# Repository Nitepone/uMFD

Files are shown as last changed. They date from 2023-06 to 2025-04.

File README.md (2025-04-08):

# uMFD: A small button pad for Pico

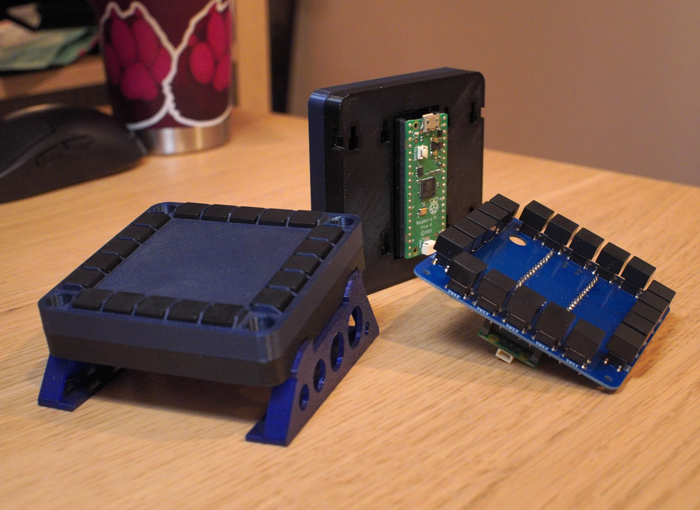
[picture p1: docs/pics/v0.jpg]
photo of hardware


This is a version 1.0 of my small mfd controller.

This repo contains the blender files for the case, along with kicad files for
the button carrier PCB, and the source code for the gamepad software.

The completed project appears as an xinput device where each of the 20 buttons
it its own digital input.

## Building

1. `mkdir build`
2. `cmake -B build`
3. `make -C build`
4. "Where is the final image?"
5. `find -name '*.uf2'`

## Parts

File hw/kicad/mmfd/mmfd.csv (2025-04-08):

# | Reference | Qty | Value | Footprint | DNP
1 | C1, C5, C6, C9, C10, C11, C12, C13, C14, C15 | 10 | 100nF | Capacitor_SMD:C_0402_1005Metric
2 | C2, C3 | 2 | 22pF | Capacitor_SMD:C_0402_1005Metric
3 | C4, C8, C16, C17 | 4 | 1uF | Capacitor_SMD:C_0402_1005Metric
4 | C7 | 1 | 10uF | Capacitor_SMD:C_0402_1005Metric
5 | F1 | 1 | 500mA | Fuse:Fuse_1206_3216Metric
6 | J1 | 1 | USB_C_Receptacle_USB2.0 | Connector_USB:USB_C_Receptacle_HRO_TYPE-C-31-M-12
7 | R1, R2, R7 | 3 | 1k | Resistor_SMD:R_0402_1005Metric
8 | R3, R4 | 2 | 5k1 | Resistor_SMD:R_0402_1005Metric
9 | R5, R6 | 2 | 27R | Resistor_SMD:R_0603_1608Metric
10 | U1 | 1 | W25Q128JVS | Package_SO:SOIC-8_5.23x5.23mm_P1.27mm
11 | U2 | 1 | USBLC6-2SC6 | Package_TO_SOT_SMD:SOT-23-6
12 | U3 | 1 | RP2040 | Sleep-Lib:RP2040-QFN-56
13 | U4 | 1 | XC6206PxxxMR-Regulator_Linear | Package_TO_SOT_SMD:SOT-23
14 | Y1 | 1 | 12MHz | Crystal:Crystal_SMD_3225-4Pin_3.2x2.5mm

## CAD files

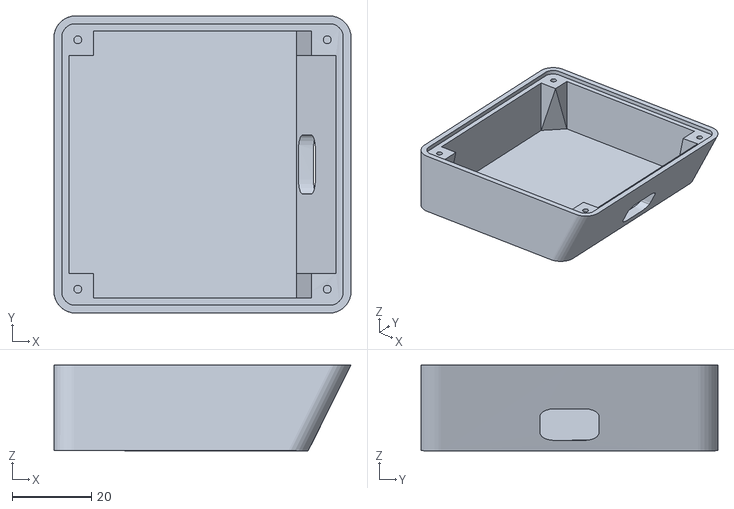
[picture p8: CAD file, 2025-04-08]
hw/blender/exports/umfd-full-v2-cleanup.stl
75.0 x 75.0 x 21.6

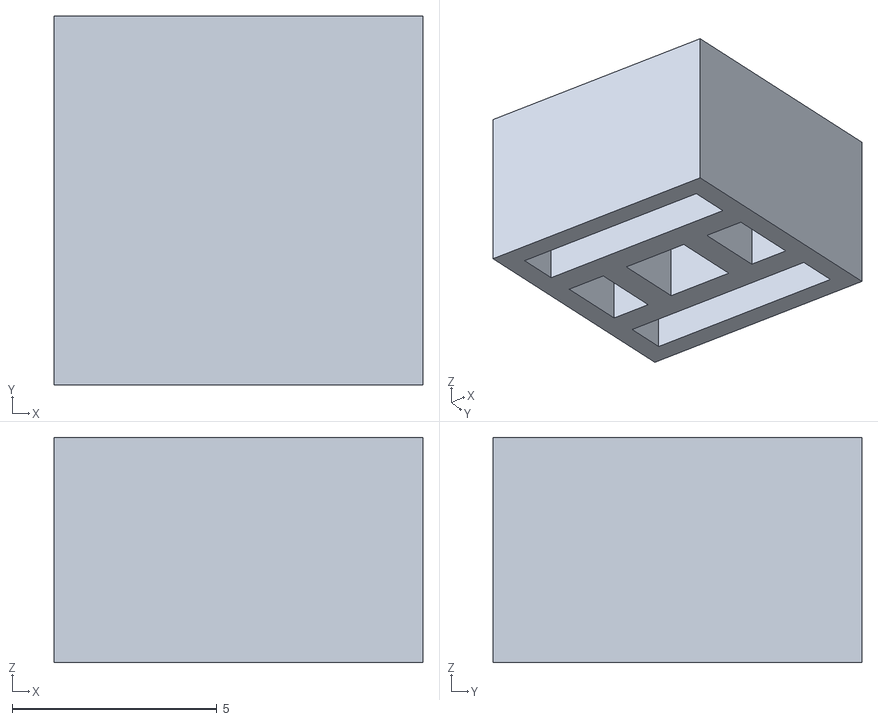
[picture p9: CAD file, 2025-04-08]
hw/blender/button.stl
9.00 x 9.00 x 5.50

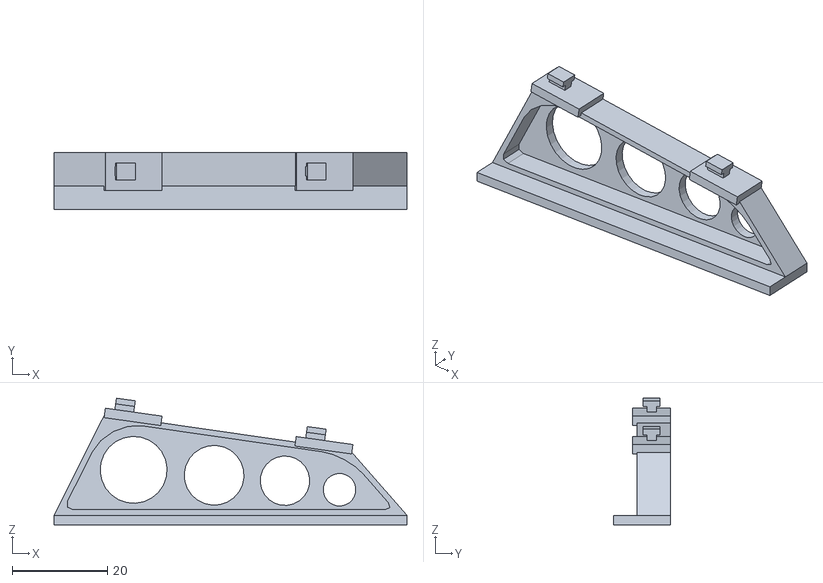
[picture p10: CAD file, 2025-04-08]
hw/blender/exports/umfd-mod-stand-v1-mirrored.stl
74.0 x 12.0 x 26.6

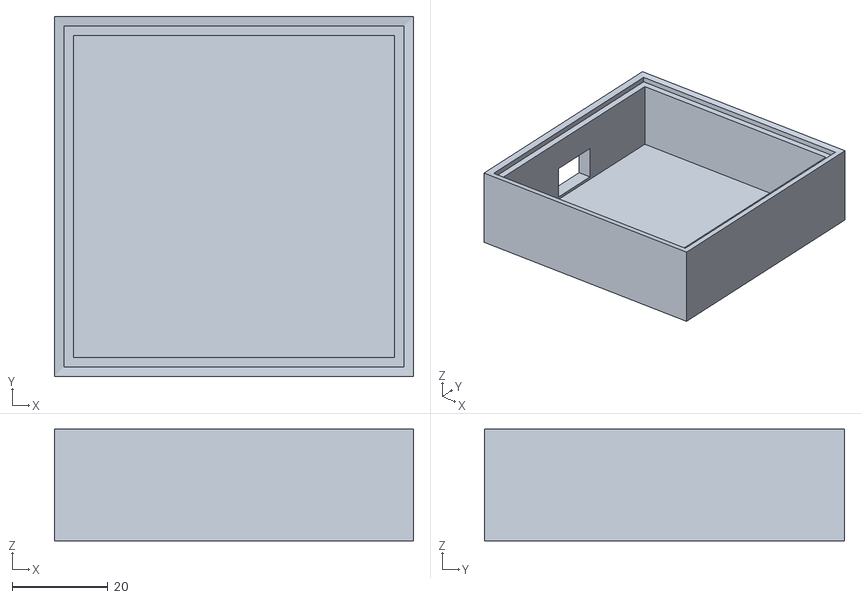
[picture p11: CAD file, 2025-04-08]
hw/kicad/untitled.stl
75.0 x 75.1 x 23.3

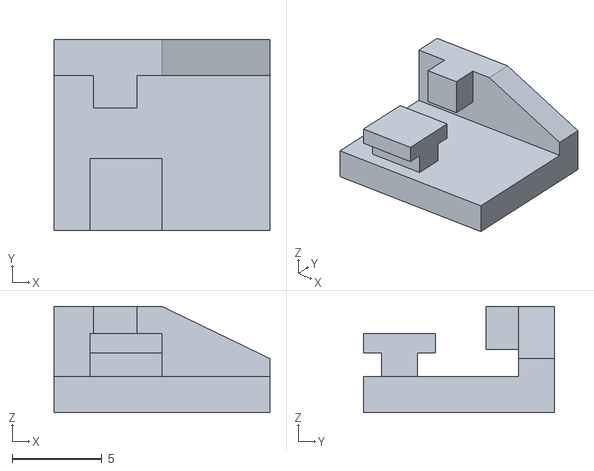
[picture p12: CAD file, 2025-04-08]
hw/blender/exports/test-mod-clip.stl
12.0 x 10.6 x 5.90

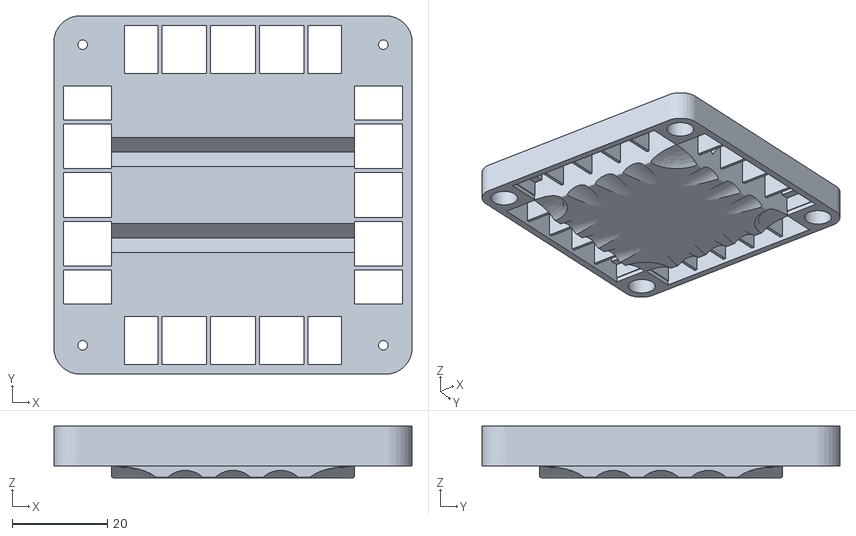
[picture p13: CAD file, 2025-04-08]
hw/blender/exports/umfd-top-cover-v3.2.stl
75.0 x 75.0 x 10.8

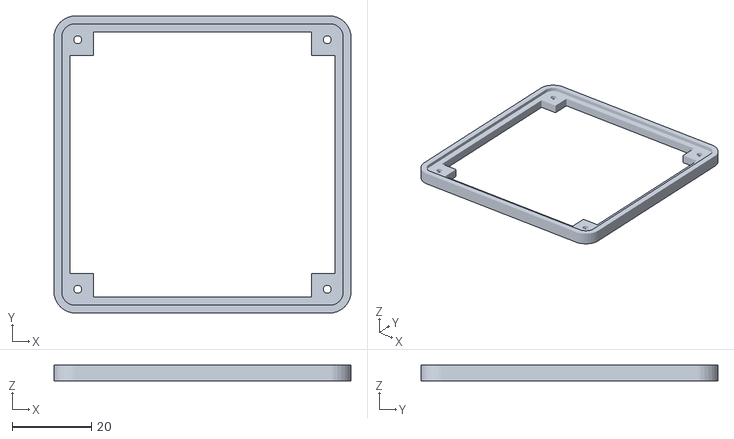
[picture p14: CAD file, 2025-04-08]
hw/blender/exports/umfd-top-v2.stl
75.0 x 75.0 x 4.00

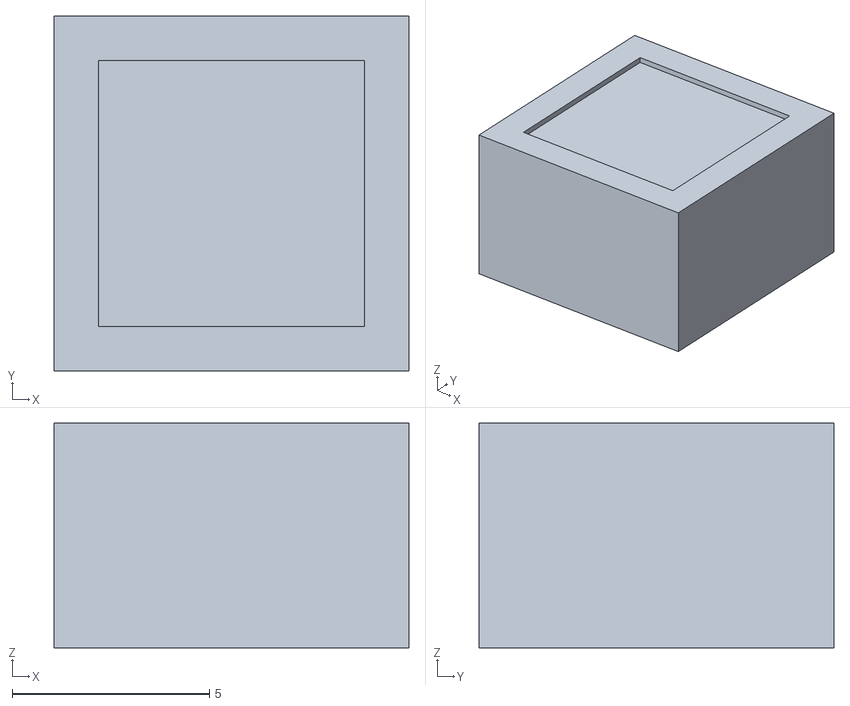
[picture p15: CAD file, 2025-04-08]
hw/blender/exports/button-v2.2.stl
9.00 x 9.00 x 5.70

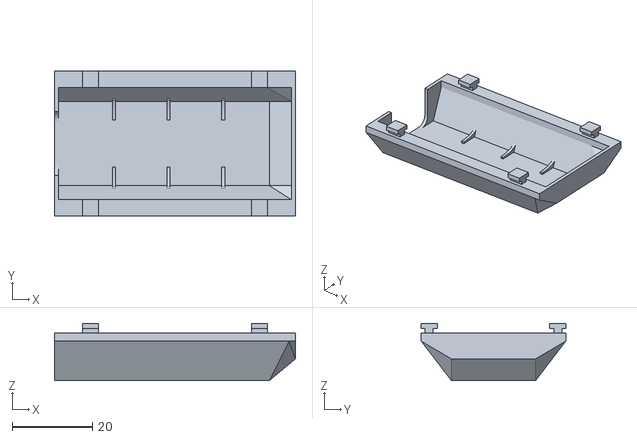
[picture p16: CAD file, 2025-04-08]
hw/blender/exports/umfd-mod-picap-v2.stl
60.0 x 36.0 x 14.2

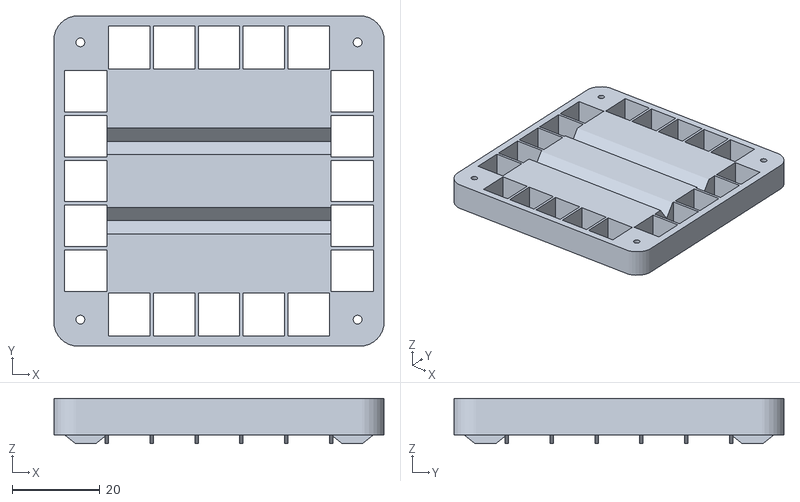
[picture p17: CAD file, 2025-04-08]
hw/blender/exports/umfd-top-cover-v3.3-cleanup.stl
75.0 x 75.0 x 10.3

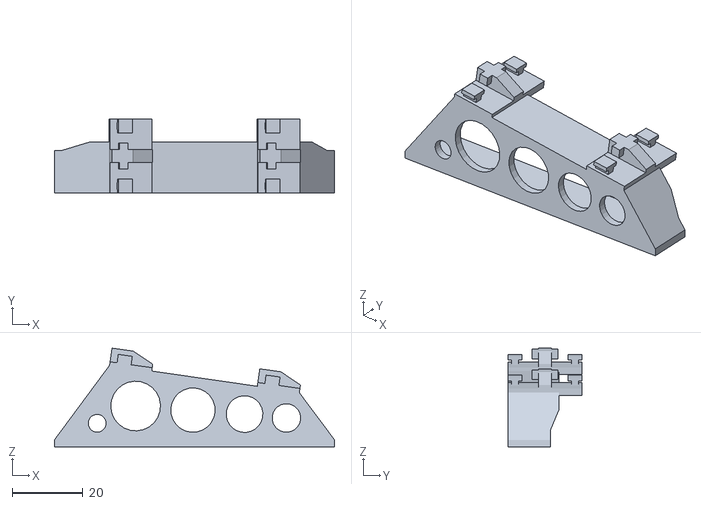
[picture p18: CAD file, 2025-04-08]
hw/blender/exports/umfd-mod-centerstand-v2.2.stl
79.0 x 21.0 x 27.9

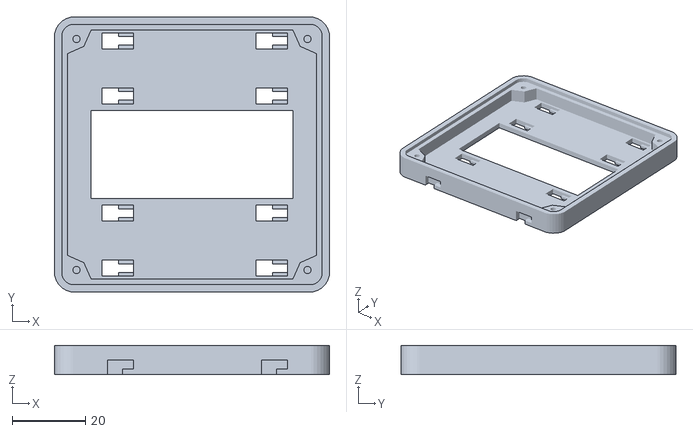
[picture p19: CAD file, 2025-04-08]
hw/blender/exports/umfd-mod-base-v2.stl
75.0 x 75.0 x 8.00

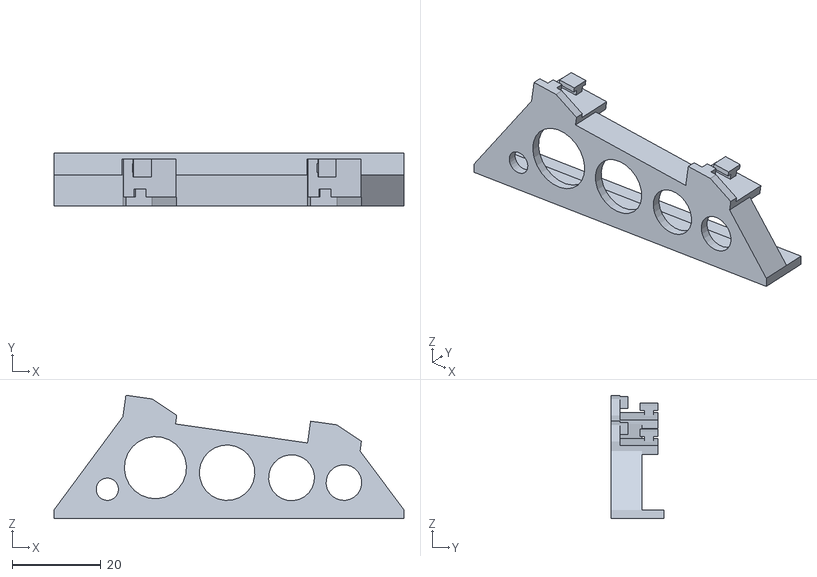
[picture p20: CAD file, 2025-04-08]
hw/blender/exports/umfd-mod-stand-v2.2.stl
79.0 x 12.0 x 27.9

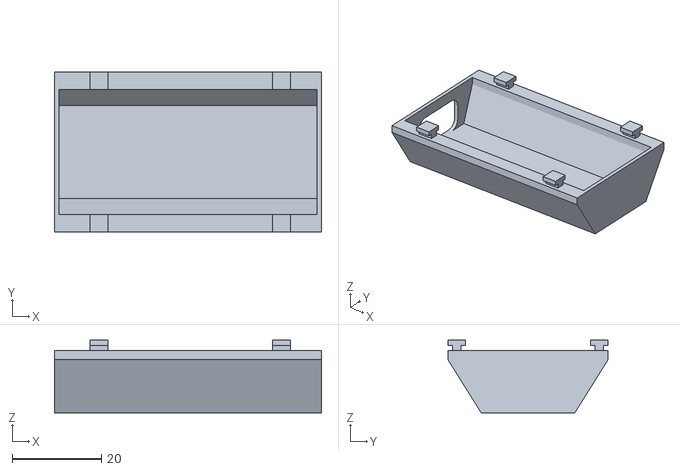
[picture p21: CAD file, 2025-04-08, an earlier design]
hw/blender/exports/umfd-mod-picap-v1.stl
60.0 x 36.0 x 16.4

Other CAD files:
hw/blender/exports/umfd-modular-top-v1.stl
hw/blender/exports/button-v2.1.stl
hw/blender/exports/umfd-mod-stand-v1.stl
hw/blender/exports/umfd-top-cover-v3.1.stl
hw/blender/button-v2.1.blend
hw/blender/button-v2.2.blend
hw/blender/button-v2.blend
hw/blender/button.blend
hw/blender/exports/button-v2.stl
hw/blender/exports/umfd-mod-stand-v2.stl
hw/blender/exports/umfd-top-cover-v1-cleanup.stl
hw/blender/exports/umfd-top-cover-v1.stl
hw/blender/exports/umfd-top-cover-v2-cleanup.stl
hw/blender/exports/umfd-top-cover-v2.1.stl
hw/blender/exports/umfd-top-cover-v3-cleanup.stl
hw/blender/exports/umfd-top-v1.1.stl
hw/blender/exports/umfd-top-v1.stl
hw/blender/umfd-full-v2-cleanup.blend
hw/blender/umfd-full-v2.1.blend
hw/blender/umfd-full-v2.blend
hw/blender/umfd-mod-base-v2.blend
hw/blender/umfd-mod-base-v2.stl
hw/blender/umfd-mod-centerstand-v2.2.blend
hw/blender/umfd-mod-picap-v1.blend
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

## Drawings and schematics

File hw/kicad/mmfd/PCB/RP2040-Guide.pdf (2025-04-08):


1 GPIO8 11 GPIO9 12 GPIO10 13 GPIO11 14 GPIO12 15 GPIO13 16 GPIO14 17 GPIO15 18 TESTEN 19 GPIO0 2 XTAL_IN 20 XTAL_OUT 21 SWCLK 24 SWDIO 25 ~{RUN} 26 GPIO16 27 GPIO17 28 GPIO18 29 GPIO1 3 GPIO19 30 GPIO20 31 GPIO21 32 GPIO22 34 GPIO23 35 GPIO24 36 GPIO25 37 GPIO26/ADC0 38 GPIO27/ADC1 39 GPIO2 4 GPIO28/ADC2 40 GPIO29/ADC3 41 ADC_AVDD 43 VREG_VIN 44 VREG_VOUT 45 D- 46 D+ 47 USB_VDD 48 GPIO3 5 DVDD 50 QSPI_SD3 51 QSPI_SCLK 52 QSPI_SD0 53 QSPI_SD2 54 QSPI_SD1 55 QSPI_SS_N 56 GND 57 GPIO4 6 GPIO5 7 GPIO6 8 GPIO7 9 U3 GND RP2040 +3.3V C6

File: RP2040-Guide.kicad_sch Sheet: / Sleepdealer

Id: 1/1 Title: RP2040 - Design Guide

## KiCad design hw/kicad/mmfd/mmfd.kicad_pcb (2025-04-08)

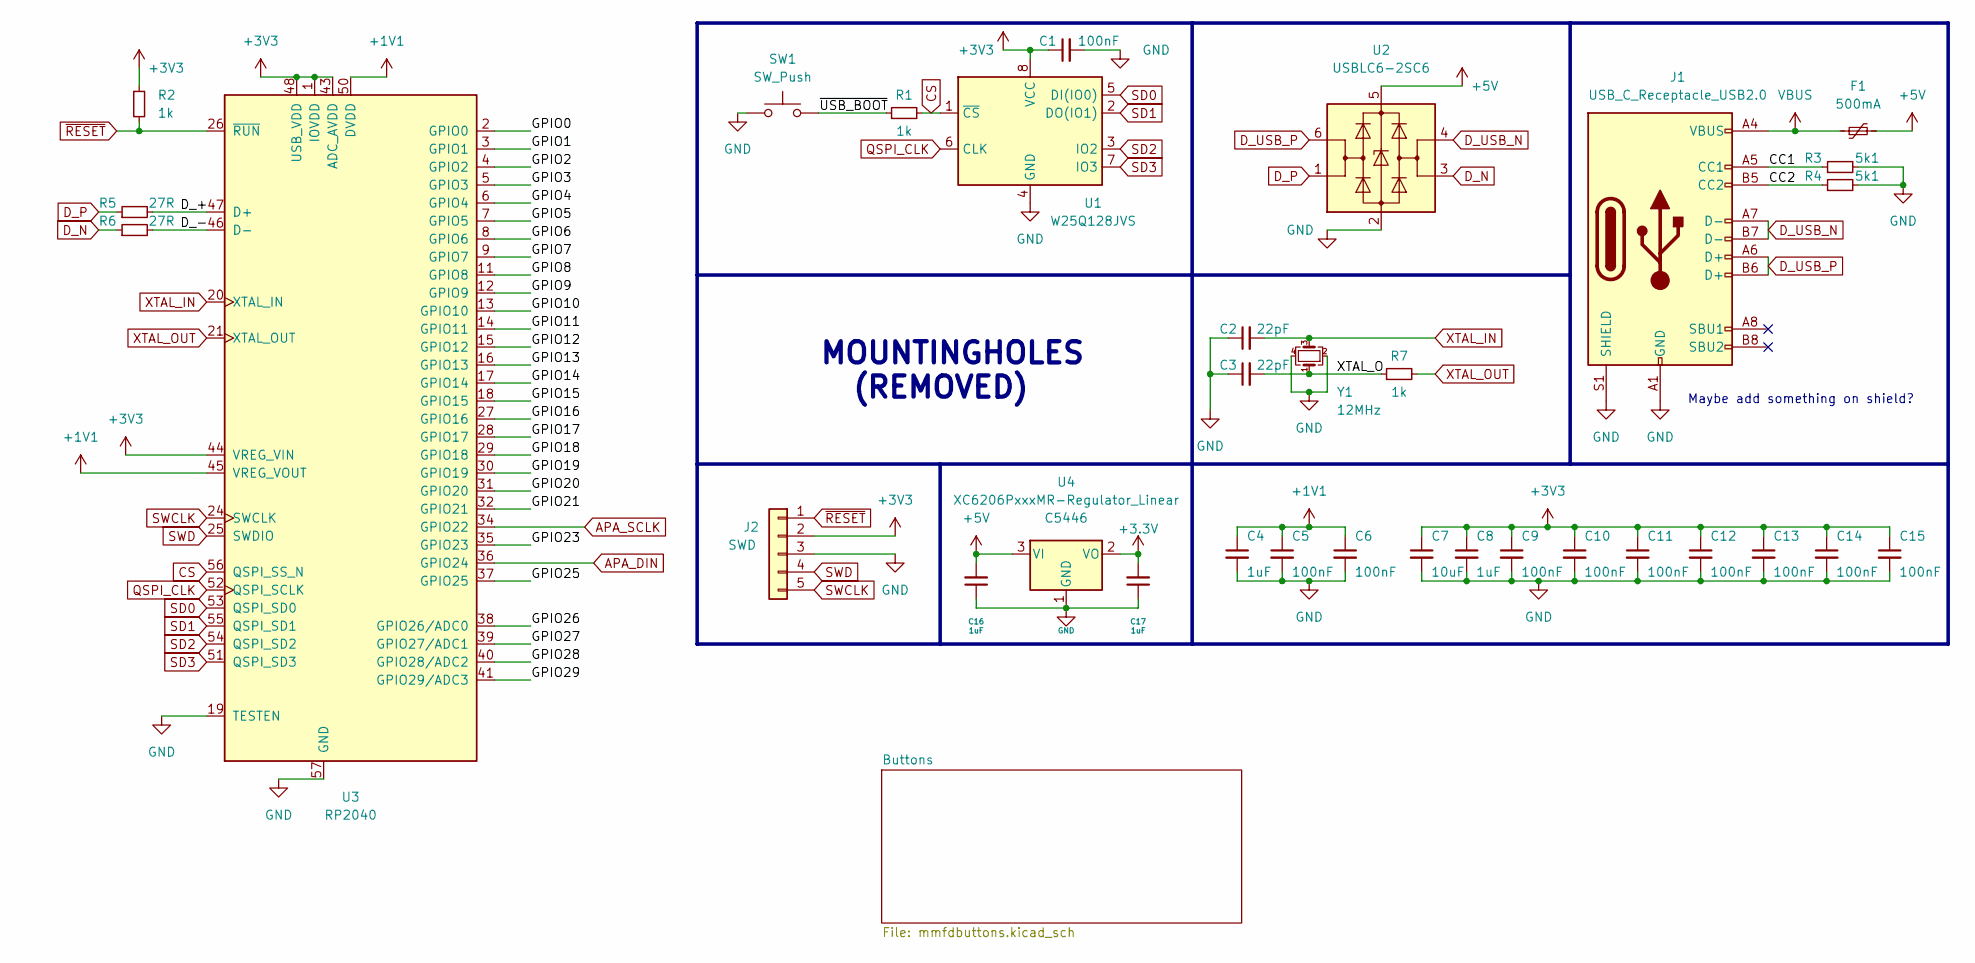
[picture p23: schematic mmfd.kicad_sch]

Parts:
C1, C5, C6, C9, C10, C11, C12, C13, C14, C15: 100nF; C_0402_1005Metric; LCSC C1525
C2, C3: 22pF; C_0402_1005Metric; LCSC C1555
C4, C8, C16, C17: 1uF; C_0402_1005Metric; LCSC C52923
C7: 10uF; C_0402_1005Metric; LCSC C15525
F1: 500mA; Fuse_1206_3216Metric; LCSC C70076
J1: USB_C_Receptacle_USB2.0; USB_C_Receptacle_HRO_TYPE-C-31-M-12; LCSC C165948
J2: SWD; PinSocket_1x05_P2.54mm_Vertical
R1, R2, R7: 1k; R_0402_1005Metric; LCSC C11702
R3, R4: 5k1; R_0402_1005Metric; LCSC C25905
R5, R6: 27R; R_0603_1608Metric; LCSC C25190
SW1: SW_Push; PinSocket_1x02_P2.54mm_Vertical
U1: W25Q128JVS; SOIC-8_5.23x5.23mm_P1.27mm; LCSC C131025
U2: USBLC6-2SC6; SOT-23-6; LCSC C2827654
U3: RP2040; RP2040-QFN-56; LCSC C2040
U4: XC6206PxxxMR-Regulator_Linear; SOT-23; LCSC C5446
Y1: 12MHz; Crystal_SMD_3225-4Pin_3.2x2.5mm; LCSC C9002

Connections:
+1V1: C4.1, C5.1, C6.1, U3.23 (DVDD), U3.45 (VREG_VOUT), U3.50 (DVDD)
+5V: C16.2, F1.2, U2.5 (VBUS), U4.3 (VI); also elsewhere on the board
/CC1: J1.A5 (CC1), R3.1
/CC2: J1.B5 (CC2), R4.1
/D_+: R5.2, U3.47 (D+)
/D_-: R6.2, U3.46 (D-)
/GPIO0: U3.2 (GPIO0)
/GPIO1: U3.3 (GPIO1)
/GPIO2: U3.4 (GPIO2)
/GPIO3: U3.5 (GPIO3)
/GPIO4: U3.6 (GPIO4)
/GPIO5: U3.7 (GPIO5)
/GPIO6: U3.8 (GPIO6)
/GPIO7: U3.9 (GPIO7)
/GPIO8: U3.11 (GPIO8)
/GPIO9: U3.12 (GPIO9)
/GPIO10: U3.13 (GPIO10)
/GPIO11: U3.14 (GPIO11)
/GPIO12: U3.15 (GPIO12)
/GPIO13: U3.16 (GPIO13)
/GPIO14: U3.17 (GPIO14)
/GPIO15: U3.18 (GPIO15)
/GPIO16: U3.27 (GPIO16)
/GPIO17: U3.28 (GPIO17)
/GPIO18: U3.29 (GPIO18)
/GPIO19: U3.30 (GPIO19)
/GPIO20: U3.31 (GPIO20)
/GPIO21: U3.32 (GPIO21)
/GPIO23: U3.35 (GPIO23)
/GPIO25: U3.37 (GPIO25)
/GPIO26: U3.38 (GPIO26/ADC0)
/GPIO27: U3.39 (GPIO27/ADC1)
/GPIO28: U3.40 (GPIO28/ADC2)
/GPIO29: U3.41 (GPIO29/ADC3)
/XTAL_O: C3.2, R7.1, Y1.1
APA_DIN: U3.36 (GPIO24); also elsewhere on the board
APA_SCLK: U3.34 (GPIO22); also elsewhere on the board
CS: R1.2, U1.1 (~CS), U3.56 (QSPI_SS_N)
D_N: R6.1, U2.3 (I/O2)
D_P: R5.1, U2.1 (I/O1)
D_USB_N: J1.A7 (D-), J1.B7 (D-), U2.4 (I/O2)
D_USB_P: J1.A6 (D+), J1.B6 (D+), U2.6 (I/O1)
QSPI_CLK: U1.6 (CLK), U3.52 (QSPI_SCLK)
SD0: U1.5 (DI(IO0)), U3.53 (QSPI_SD0)
SD1: U1.2 (DO(IO1)), U3.55 (QSPI_SD1)
SD2: U1.3 (IO2), U3.54 (QSPI_SD2)
SD3: U1.7 (IO3), U3.51 (QSPI_SD3)
SWCLK: J2.5, U3.24 (SWCLK)
SWD: J2.4, U3.25 (SWDIO)
VBUS: F1.1, J1.A4 (VBUS), J1.A9 (VBUS), J1.B4 (VBUS), J1.B9 (VBUS)
XTAL_IN: C2.2, U3.20 (XTAL_IN), Y1.3
XTAL_OUT: R7.2, U3.21 (XTAL_OUT)
~RESET: J2.1, R2.2, U3.26 (~RUN)

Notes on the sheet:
MOUNTINGHOLES (REMOVED)
Maybe add something on shield?

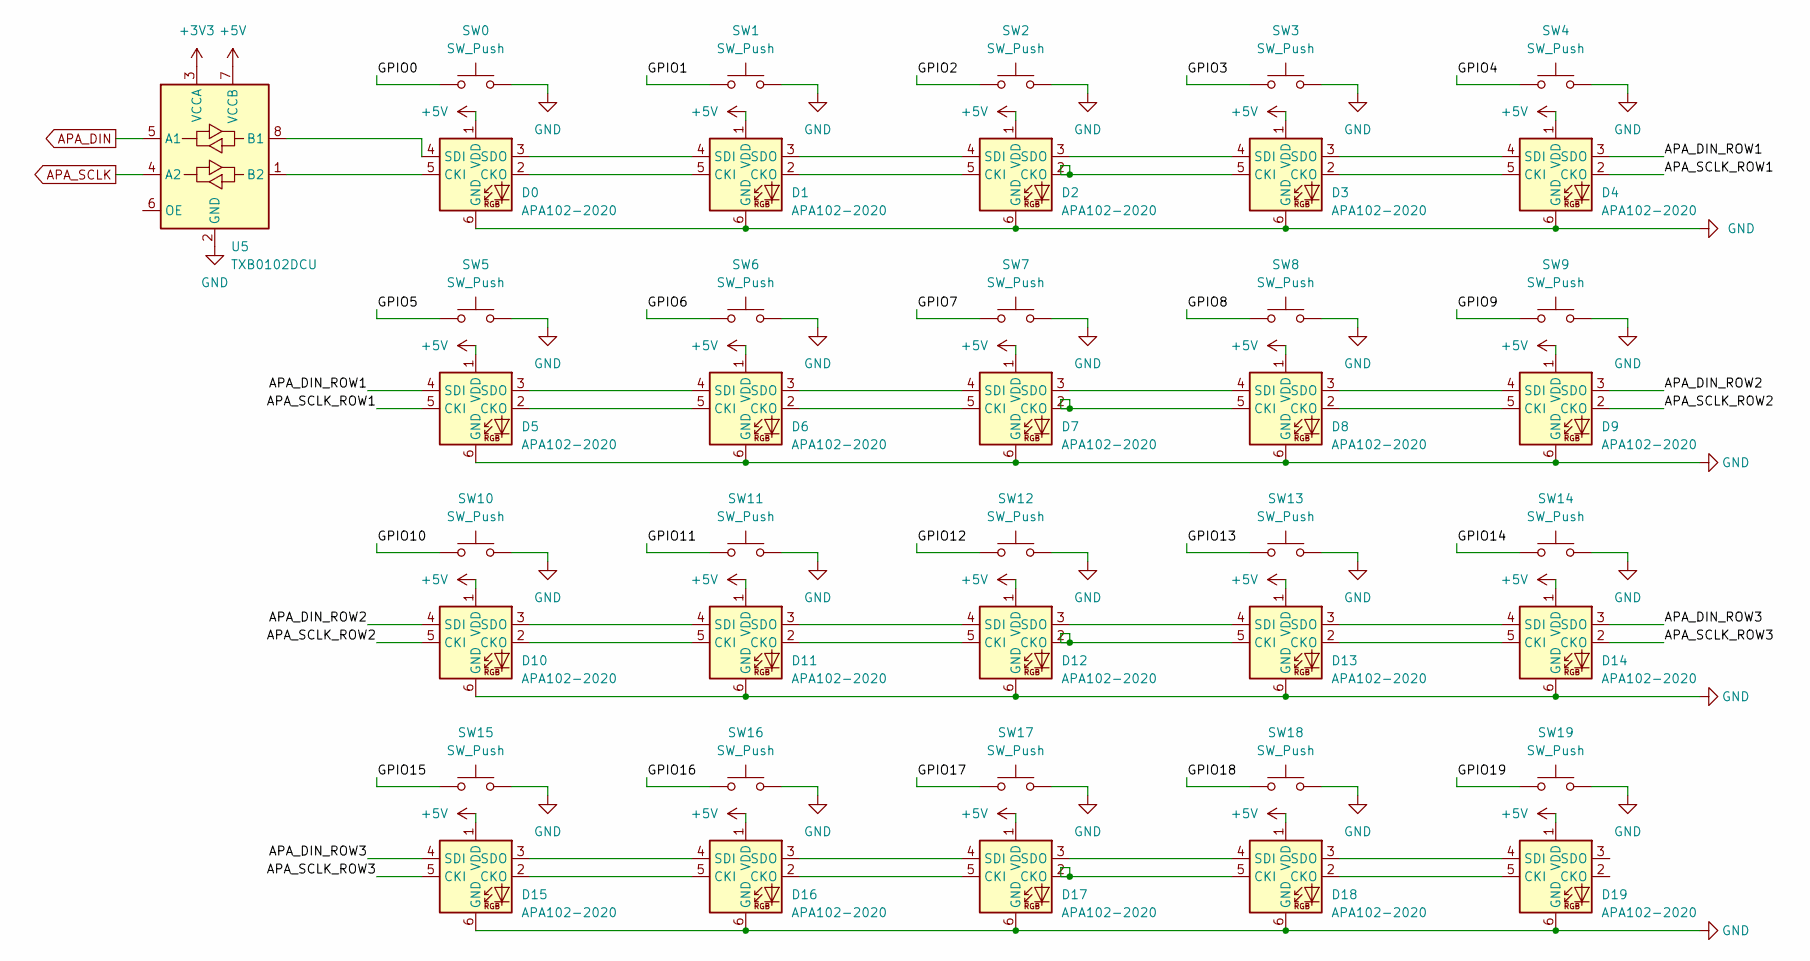
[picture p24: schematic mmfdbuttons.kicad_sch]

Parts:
D0, D1, D2, D3, D4, D5, D6, D7, D8, D9, D10, D11, D12, D13, D14, D15, D16, D17, D18, D19: APA102-2020; LED-APA102-2020
SW0, SW1, SW2, SW3, SW4, SW5, SW6, SW7, SW8, SW9, SW10, SW11, SW12, SW13, SW14, SW15, SW16, SW17, SW18, SW19: SW_Push; Kailh_socket_MX_optional
U5: TXB0102DCU; VSSOP-8_2.4x2.1mm_P0.5mm

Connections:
+5V: D0.1 (VDD), D1.1 (VDD), D2.1 (VDD), D3.1 (VDD), D4.1 (VDD), D5.1 (VDD), D6.1 (VDD), D7.1 (VDD), D8.1 (VDD), D9.1 (VDD), D10.1 (VDD), D11.1 (VDD), D12.1 (VDD), D13.1 (VDD), D14.1 (VDD), D15.1 (VDD), D16.1 (VDD), D17.1 (VDD), D18.1 (VDD), D19.1 (VDD), U5.7 (VCCB); also elsewhere on the board
/Buttons/APA_DIN_ROW1: D4.3 (SDO), D5.4 (SDI)
/Buttons/APA_DIN_ROW2: D9.3 (SDO), D10.4 (SDI)
/Buttons/APA_DIN_ROW3: D14.3 (SDO), D15.4 (SDI)
/Buttons/APA_SCLK_ROW1: D4.2 (CKO), D5.5 (CKI)
/Buttons/APA_SCLK_ROW2: D9.2 (CKO), D10.5 (CKI)
/Buttons/APA_SCLK_ROW3: D14.2 (CKO), D15.5 (CKI)
/Buttons/GPIO0: SW0.1
/Buttons/GPIO2: SW2.1
/Buttons/GPIO3: SW3.1
/Buttons/GPIO4: SW4.1
/Buttons/GPIO5: SW5.1
/Buttons/GPIO6: SW6.1
/Buttons/GPIO7: SW7.1
/Buttons/GPIO8: SW8.1
/Buttons/GPIO9: SW9.1
/Buttons/GPIO10: SW10.1
/Buttons/GPIO11: SW11.1
/Buttons/GPIO12: SW12.1
/Buttons/GPIO13: SW13.1
/Buttons/GPIO14: SW14.1
/Buttons/GPIO15: SW15.1
/Buttons/GPIO16: SW16.1
/Buttons/GPIO17: SW17.1
/Buttons/GPIO18: SW18.1
/Buttons/GPIO19: SW19.1
APA_DIN: U5.5 (A1); also elsewhere on the board
APA_SCLK: U5.4 (A2); also elsewhere on the board
unnamed: D0.5 (CKI), U5.1 (B2)
unnamed: D0.2 (CKO), D1.5 (CKI)
unnamed: D0.4 (SDI), U5.8 (B1)
unnamed: D0.3 (SDO), D1.4 (SDI)
unnamed: D1.2 (CKO), D2.5 (CKI)
unnamed: D1.3 (SDO), D2.4 (SDI)
unnamed: D2.2 (CKO), D3.5 (CKI)
unnamed: D2.3 (SDO), D3.4 (SDI)
unnamed: D3.2 (CKO), D4.5 (CKI)
unnamed: D3.3 (SDO), D4.4 (SDI)
unnamed: D5.2 (CKO), D6.5 (CKI)
unnamed: D5.3 (SDO), D6.4 (SDI)
unnamed: D6.2 (CKO), D7.5 (CKI)
unnamed: D6.3 (SDO), D7.4 (SDI)
unnamed: D7.2 (CKO), D8.5 (CKI)
unnamed: D7.3 (SDO), D8.4 (SDI)
unnamed: D8.2 (CKO), D9.5 (CKI)
unnamed: D8.3 (SDO), D9.4 (SDI)
unnamed: D10.2 (CKO), D11.5 (CKI)
unnamed: D10.3 (SDO), D11.4 (SDI)
unnamed: D11.2 (CKO), D12.5 (CKI)
unnamed: D11.3 (SDO), D12.4 (SDI)
unnamed: D12.2 (CKO), D13.5 (CKI)
unnamed: D12.3 (SDO), D13.4 (SDI)
unnamed: D13.2 (CKO), D14.5 (CKI)
unnamed: D13.3 (SDO), D14.4 (SDI)
unnamed: D15.2 (CKO), D16.5 (CKI)
unnamed: D15.3 (SDO), D16.4 (SDI)
unnamed: D16.2 (CKO), D17.5 (CKI)
unnamed: D16.3 (SDO), D17.4 (SDI)
unnamed: D17.2 (CKO), D18.5 (CKI)
unnamed: D17.3 (SDO), D18.4 (SDI)
unnamed: D18.2 (CKO), D19.5 (CKI)
unnamed: D18.3 (SDO), D19.4 (SDI)

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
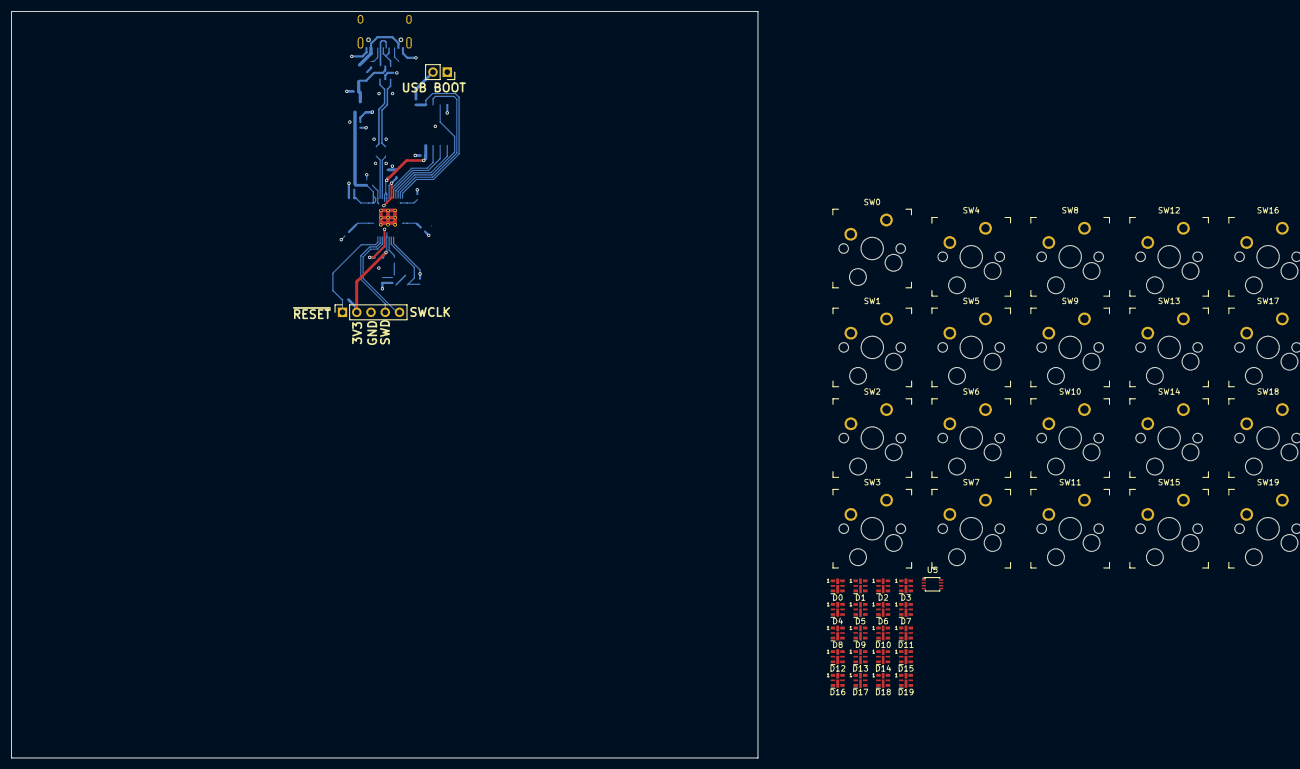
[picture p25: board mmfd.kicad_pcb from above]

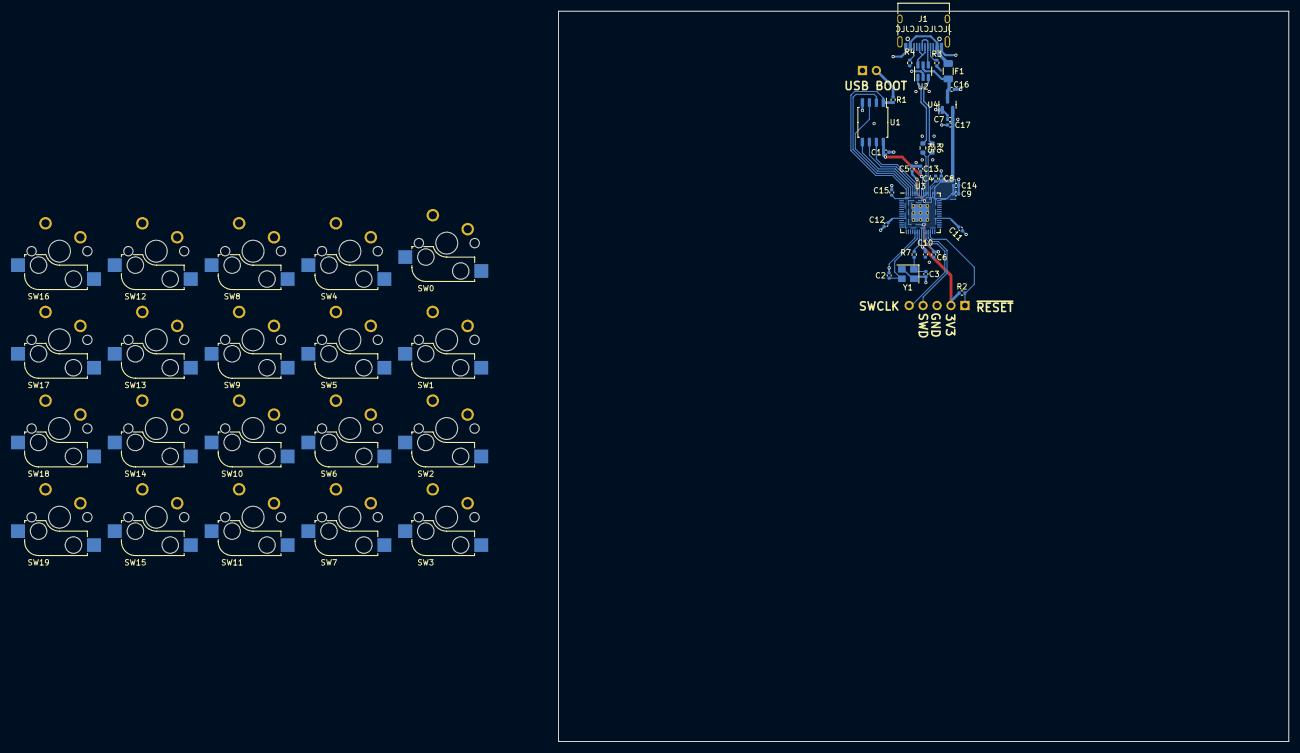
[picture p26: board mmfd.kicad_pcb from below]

Board: 2 copper layers, 133.0 x 133.0 mm, 74 parts (31 on the bottom side), 68 nets.

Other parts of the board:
SW20: SW_Push; PinSocket_1x02_P2.54mm_Vertical

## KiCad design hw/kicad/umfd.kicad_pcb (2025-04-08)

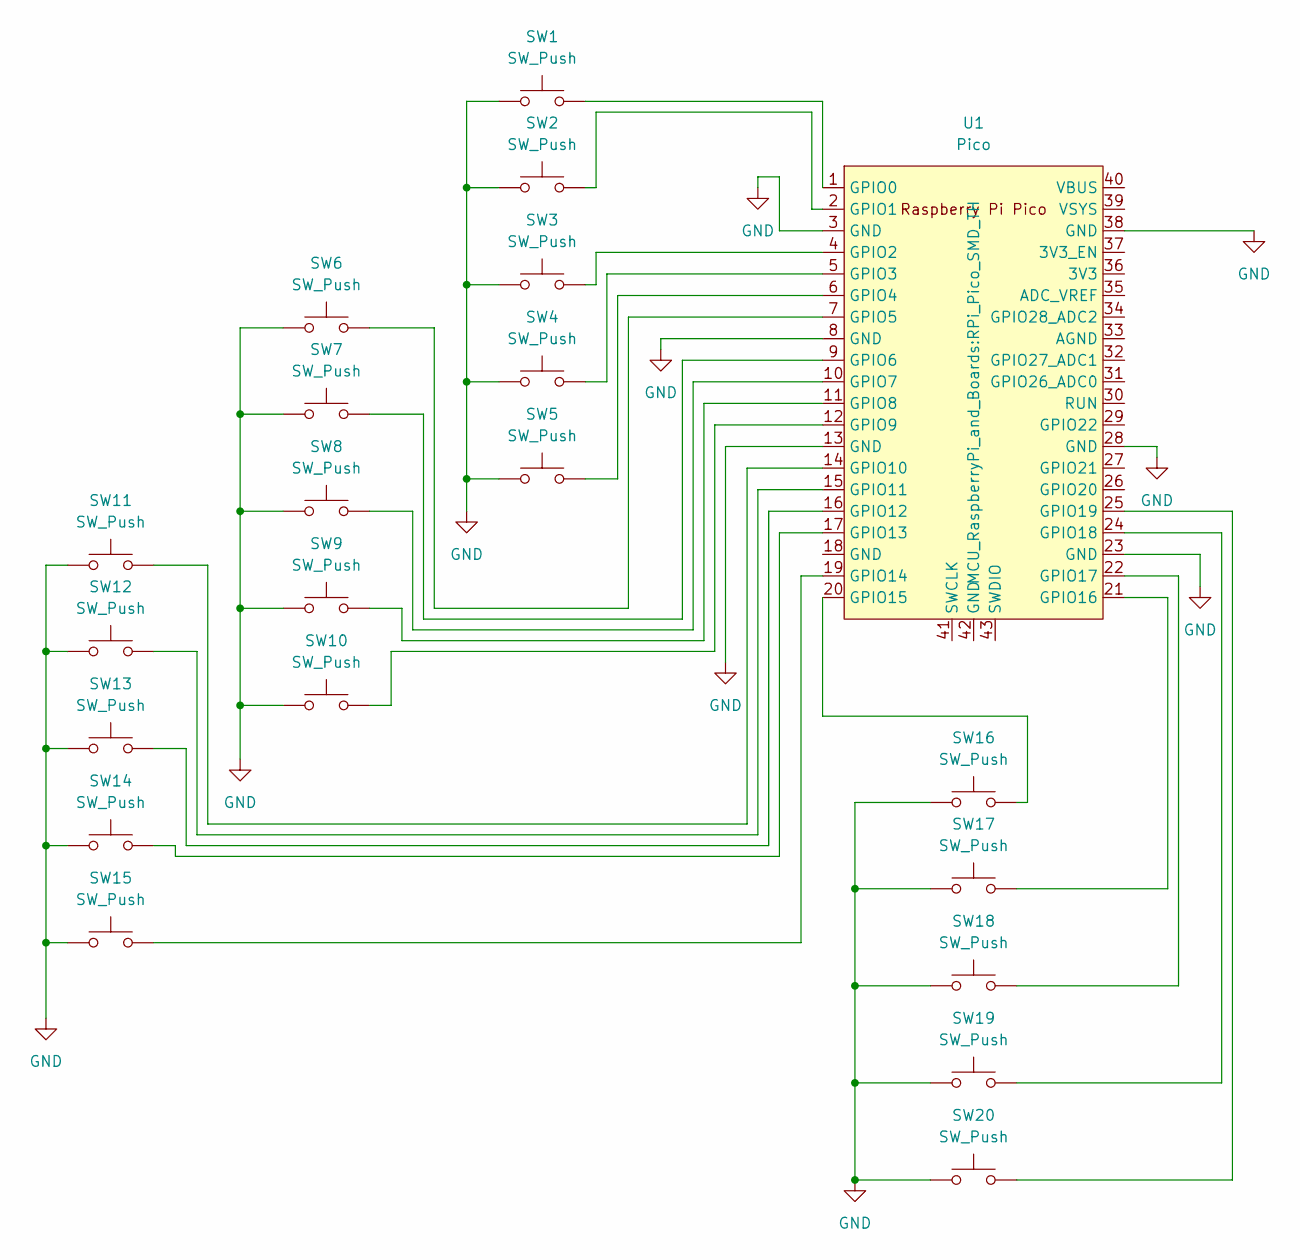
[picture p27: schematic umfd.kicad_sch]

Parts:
SW1, SW2, SW3, SW4, SW5, SW6, SW7, SW8, SW9, SW10, SW11, SW12, SW13, SW14, SW15, SW16, SW17, SW18, SW19, SW20: SW_Push; SW_PUSH_6mm
U1: Pico; RPi_Pico_SMD_TH

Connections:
GND: SW1.1, SW2.1, SW3.1, SW4.1, SW5.1, SW6.1, SW7.1, SW8.1, SW9.1, SW10.1, SW11.1, SW12.1, SW13.1, SW14.1, SW15.1, SW16.1, SW17.1, SW18.1, SW19.1, SW20.1, U1.3 (GND), U1.8 (GND), U1.13 (GND), U1.23 (GND), U1.28 (GND), U1.38 (GND)
unnamed: SW1.2, U1.1 (GPIO0)
unnamed: SW2.2, U1.2 (GPIO1)
unnamed: SW3.2, U1.4 (GPIO2)
unnamed: SW4.2, U1.5 (GPIO3)
unnamed: SW5.2, U1.6 (GPIO4)
unnamed: SW6.2, U1.7 (GPIO5)
unnamed: SW7.2, U1.9 (GPIO6)
unnamed: SW8.2, U1.10 (GPIO7)
unnamed: SW9.2, U1.11 (GPIO8)
unnamed: SW10.2, U1.12 (GPIO9)
unnamed: SW11.2, U1.14 (GPIO10)
unnamed: SW12.2, U1.15 (GPIO11)
unnamed: SW13.2, U1.16 (GPIO12)
unnamed: SW14.2, U1.17 (GPIO13)
unnamed: SW15.2, U1.19 (GPIO14)
unnamed: SW16.2, U1.20 (GPIO15)
unnamed: SW17.2, U1.21 (GPIO16)
unnamed: SW18.2, U1.22 (GPIO17)
unnamed: SW19.2, U1.24 (GPIO18)
unnamed: SW20.2, U1.25 (GPIO19)

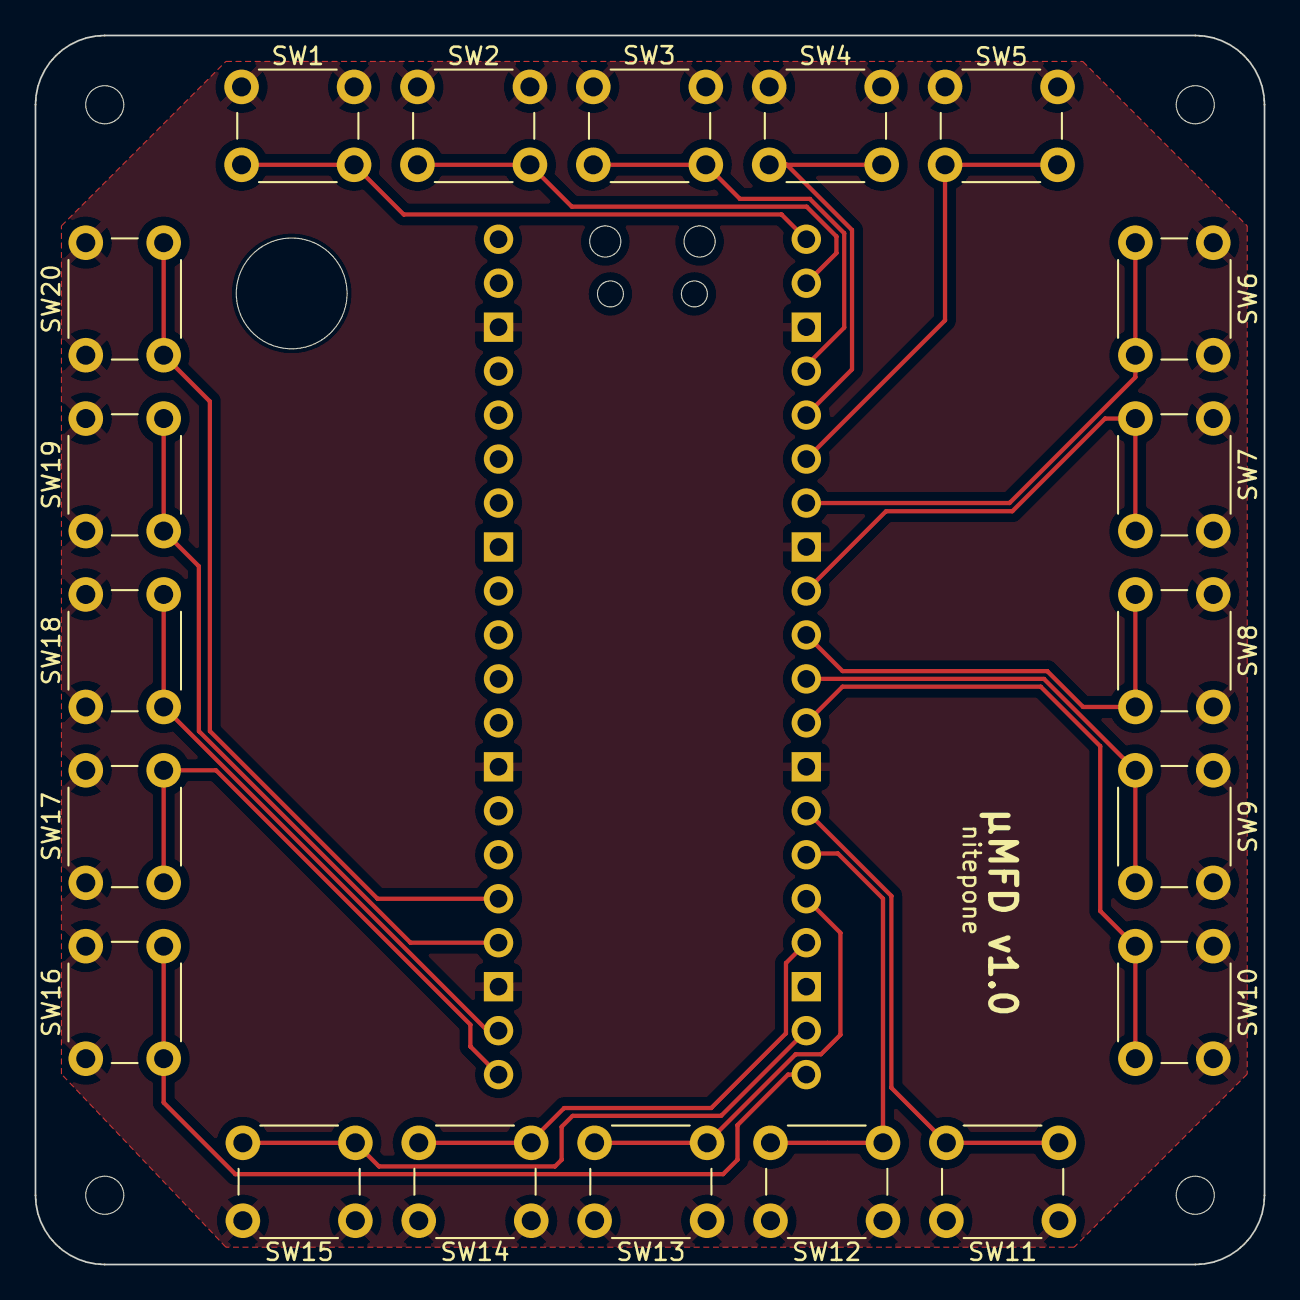
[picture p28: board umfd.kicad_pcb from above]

Board: 2 copper layers, 71.0 x 71.0 mm, 26 parts (1 on the bottom side), 21 nets.

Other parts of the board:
hole: MountingHole_6.4mm_M6_ISO14580
m1, m2, m3, m4: MountingHole_2.2mm_M2

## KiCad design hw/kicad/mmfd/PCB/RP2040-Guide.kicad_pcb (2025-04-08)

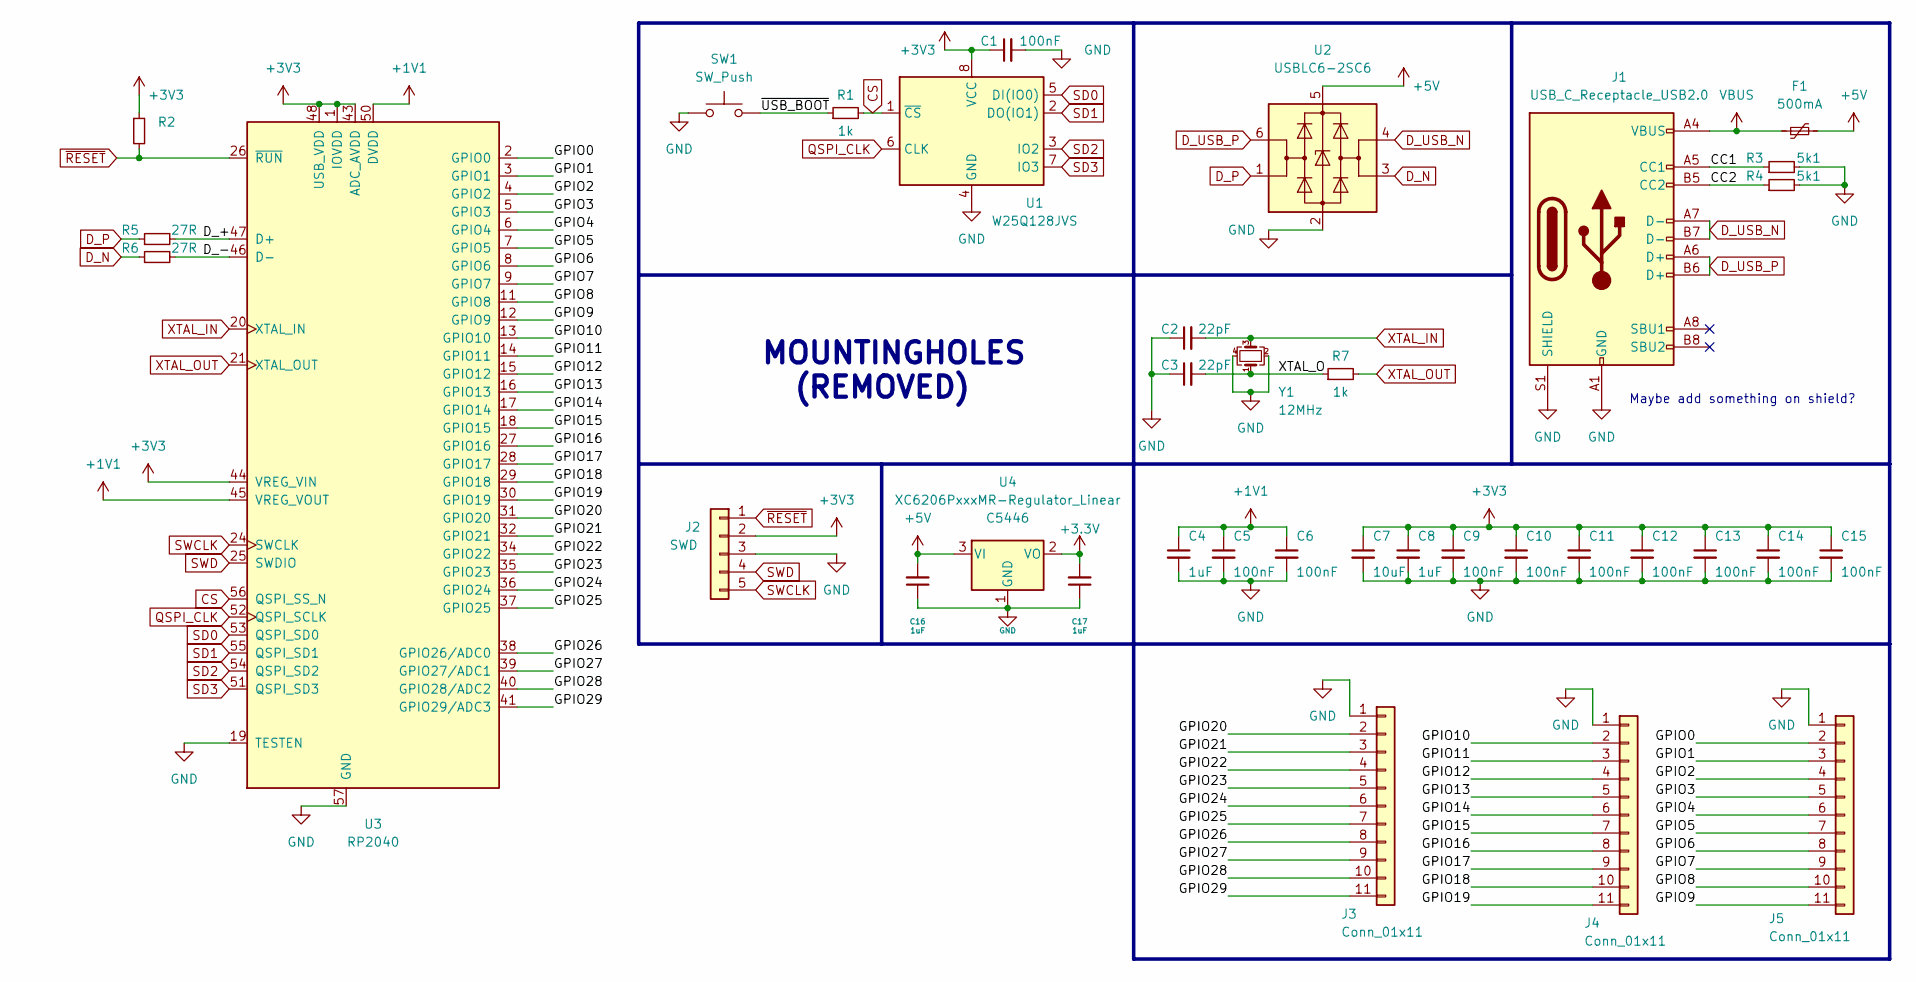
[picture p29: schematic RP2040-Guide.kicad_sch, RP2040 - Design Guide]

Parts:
C1, C5, C6, C9, C10, C11, C12, C13, C14, C15: 100nF; C_0402_1005Metric; LCSC C1525
C2, C3: 22pF; C_0402_1005Metric; LCSC C1555
C4, C8, C16, C17: 1uF; C_0402_1005Metric; LCSC C52923
C7: 10uF; C_0402_1005Metric; LCSC C15525
F1: 500mA; Fuse_1206_3216Metric; LCSC C70076
J1: USB_C_Receptacle_USB2.0; USB_C_Receptacle_HRO_TYPE-C-31-M-12; LCSC C165948
J2: SWD; PinSocket_1x05_P2.54mm_Vertical
J3, J4, J5: Conn_01x11; PinSocket_1x11_P2.54mm_Vertical
R1, R7: 1k; R_0402_1005Metric; LCSC C11702
R2: LCSC C11702
R3, R4: 5k1; R_0402_1005Metric; LCSC C25905
R5, R6: 27R; R_0603_1608Metric; LCSC C25190
SW1: SW_Push; PinSocket_1x02_P2.54mm_Vertical
U1: W25Q128JVS; SOIC-8_5.23x5.23mm_P1.27mm; LCSC C131025
U2: USBLC6-2SC6; SOT-23-6; LCSC C2827654
U3: RP2040; RP2040-QFN-56; LCSC C2040
U4: XC6206PxxxMR-Regulator_Linear; SOT-23; LCSC C5446
Y1: 12MHz; Crystal_SMD_3225-4Pin_3.2x2.5mm; LCSC C9002

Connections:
+1V1: C4.1, C5.1, C6.1, U3.23 (DVDD), U3.45 (VREG_VOUT), U3.50 (DVDD)
+5V: C16.2, F1.2, U2.5 (VBUS), U4.3 (VI)
/CC1: J1.A5 (CC1), R3.1
/CC2: J1.B5 (CC2), R4.1
/D_+: R5.2, U3.47 (D+)
/D_-: R6.2, U3.46 (D-)
/GPIO0: J5.2, U3.2 (GPIO0)
/GPIO1: J5.3, U3.3 (GPIO1)
/GPIO2: J5.4, U3.4 (GPIO2)
/GPIO3: J5.5, U3.5 (GPIO3)
/GPIO4: J5.6, U3.6 (GPIO4)
/GPIO5: J5.7, U3.7 (GPIO5)
/GPIO6: J5.8, U3.8 (GPIO6)
/GPIO7: J5.9, U3.9 (GPIO7)
/GPIO8: J5.10, U3.11 (GPIO8)
/GPIO9: J5.11, U3.12 (GPIO9)
/GPIO10: J4.2, U3.13 (GPIO10)
/GPIO11: J4.3, U3.14 (GPIO11)
/GPIO12: J4.4, U3.15 (GPIO12)
/GPIO13: J4.5, U3.16 (GPIO13)
/GPIO14: J4.6, U3.17 (GPIO14)
/GPIO15: J4.7, U3.18 (GPIO15)
/GPIO16: J4.8, U3.27 (GPIO16)
/GPIO17: J4.9, U3.28 (GPIO17)
/GPIO18: J4.10, U3.29 (GPIO18)
/GPIO19: J4.11, U3.30 (GPIO19)
/GPIO20: J3.2, U3.31 (GPIO20)
/GPIO21: J3.3, U3.32 (GPIO21)
/GPIO22: J3.4, U3.34 (GPIO22)
/GPIO23: J3.5, U3.35 (GPIO23)
/GPIO24: J3.6, U3.36 (GPIO24)
/GPIO25: J3.7, U3.37 (GPIO25)
/GPIO26: J3.8, U3.38 (GPIO26/ADC0)
/GPIO27: J3.9, U3.39 (GPIO27/ADC1)
/GPIO28: J3.10, U3.40 (GPIO28/ADC2)
/GPIO29: J3.11, U3.41 (GPIO29/ADC3)
/XTAL_O: C3.2, R7.1, Y1.1
/~USB_BOOT: R1.1, SW1.2
CS: R1.2, U1.1 (~CS), U3.56 (QSPI_SS_N)
D_N: R6.1, U2.3 (I/O2)
D_P: R5.1, U2.1 (I/O1)
D_USB_N: J1.A7 (D-), J1.B7 (D-), U2.4 (I/O2)
D_USB_P: J1.A6 (D+), J1.B6 (D+), U2.6 (I/O1)
GND: C1.2, C2.1, C3.1, C4.2, C5.2, C6.2, C7.2, C8.2, C9.2, C10.2, C11.2, C12.2, C13.2, C14.2, C15.2, C16.1, C17.1, J1.A1 (GND), J1.A12 (GND), J1.B1 (GND), J1.B12 (GND), J1.S1 (SHIELD), J2.3, J3.1, J4.1, J5.1, R3.2, R4.2, SW1.1, U1.4 (GND), U2.2 (GND), U3.19 (TESTEN), U3.57 (GND), U4.1 (GND), Y1.2, Y1.4
QSPI_CLK: U1.6 (CLK), U3.52 (QSPI_SCLK)
SD0: U1.5 (DI(IO0)), U3.53 (QSPI_SD0)
SD1: U1.2 (DO(IO1)), U3.55 (QSPI_SD1)
SD2: U1.3 (IO2), U3.54 (QSPI_SD2)
SD3: U1.7 (IO3), U3.51 (QSPI_SD3)
SWCLK: J2.5, U3.24 (SWCLK)
SWD: J2.4, U3.25 (SWDIO)
VBUS: F1.1, J1.A4 (VBUS), J1.A9 (VBUS), J1.B4 (VBUS), J1.B9 (VBUS)
XTAL_IN: C2.2, U3.20 (XTAL_IN), Y1.3
XTAL_OUT: R7.2, U3.21 (XTAL_OUT)
~RESET: J2.1, R2.2, U3.26 (~RUN)

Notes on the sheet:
MOUNTINGHOLES (REMOVED)
Maybe add something on shield?

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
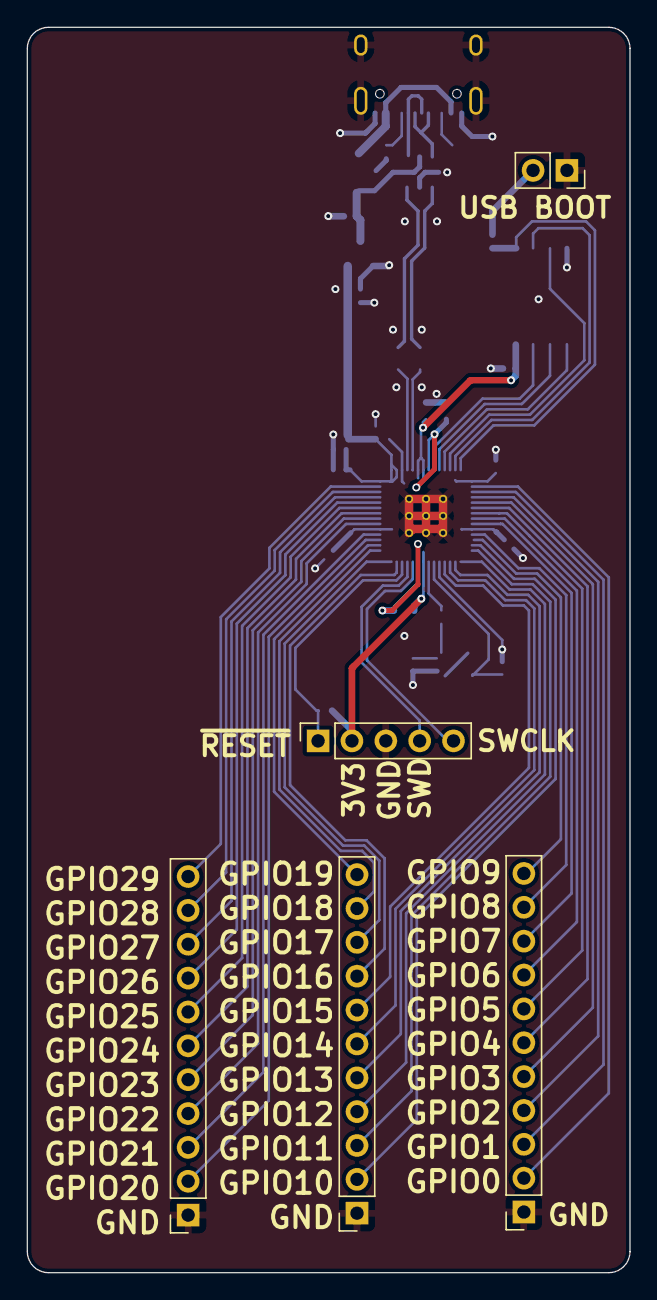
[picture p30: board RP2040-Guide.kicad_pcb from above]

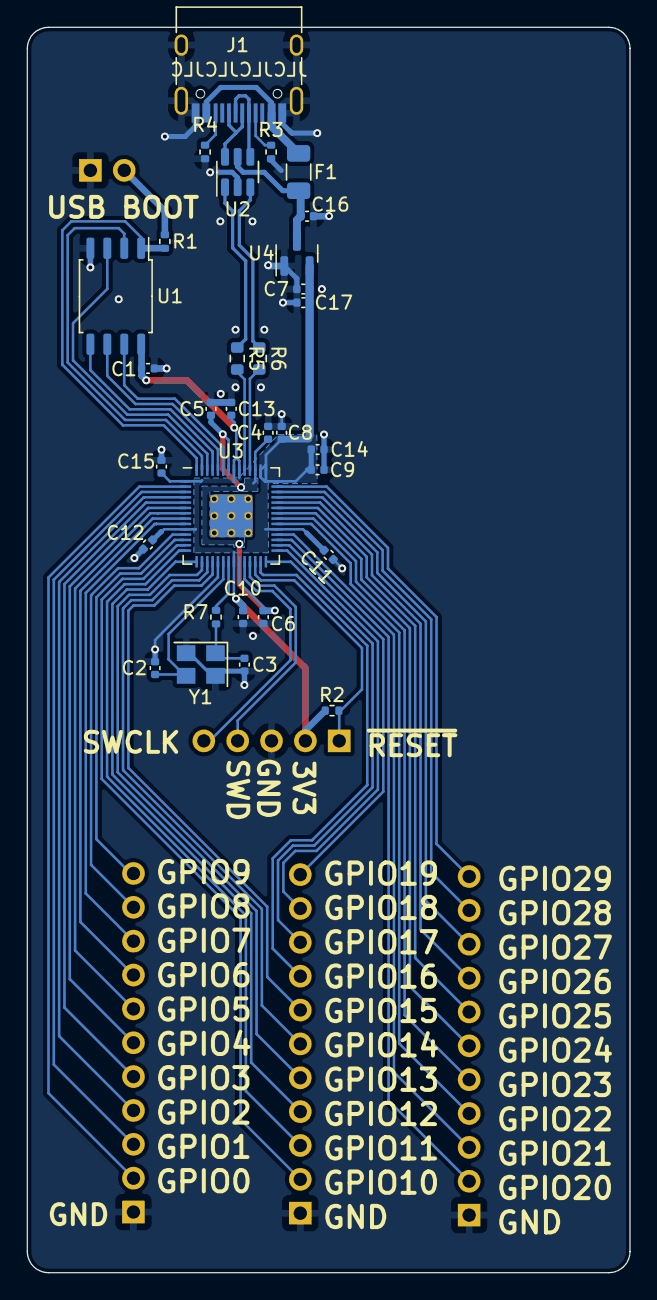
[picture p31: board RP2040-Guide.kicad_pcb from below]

Board: 2 copper layers, 45.2 x 93.4 mm, 36 parts (31 on the bottom side), 56 nets.

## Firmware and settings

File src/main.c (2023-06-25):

/*
 * Pi Pico USB Direct Input Controller Implementation.
 *
 * Author: Luna Hart <nitepone>
 */

#include <stdio.h>
#include <stdlib.h>
#include <string.h>

#include "bsp/board.h"
#include "hardware/gpio.h"
#include "pico/stdlib.h"
#include "tusb.h"

#include "usb_descriptors.h"

#define MAX_DINPUT_BTN_ID 31

struct dinput_btn_reg {
    bool state;
    uint8_t btn_id;
};

struct gpio_state {
    bool last;
    uint32_t hist;
};

struct phy_btn_reg {
    bool enabled_state;
    uint8_t gpio_id;
    uint32_t gpio_debounce_mask;
    struct gpio_state gpio_state;
    struct dinput_btn_reg* d_btn;
};


static uint32_t blink_interval_ms = 1500;
struct dinput_btn_reg global_d_btns[32];
uint8_t global_d_btn_cnt = 0;
uint8_t global_hat_state = 0;

void led_blinking_task(void);
void hid_task(void);

void reg_dinput_btn(struct dinput_btn_reg* d_btn_reg, uint8_t btn_id) {
    d_btn_reg->state = 0;
    d_btn_reg->btn_id = btn_id;
}

void reg_btn(struct phy_btn_reg* btn_reg, struct dinput_btn_reg* d_btn_reg, uint8_t gpio_id, bool enabled_state) {
    if (!btn_reg) {
        return;
    }
    memset(btn_reg, 0, sizeof(*btn_reg));
    btn_reg->enabled_state = enabled_state;
    btn_reg->gpio_id = gpio_id;
    btn_reg->gpio_debounce_mask = 0x0f;
    btn_reg->d_btn = d_btn_reg;
}

void poll_registered_gpios(struct phy_btn_reg* btn_arr, uint16_t btn_arr_len) {
    struct phy_btn_reg* btn = NULL;
    uint32_t raw_gpio = gpio_get_all();
    uint32_t gpio_hist_window = 0;

    for (btn = btn_arr; btn < (btn_arr + btn_arr_len); btn++) {
        // check if button is supposed to change
        btn->gpio_state.hist = (btn->gpio_state.hist << 1)
                | ((raw_gpio >> btn->gpio_id) & 0x1);
        gpio_hist_window = (btn->gpio_state.hist) & btn->gpio_debounce_mask;
        if ( gpio_hist_window == 0 || gpio_hist_window == btn->gpio_debounce_mask ) {
            if ((gpio_hist_window & 1) == btn->enabled_state) {
                btn->d_btn->state = true;
            }
            else {
                btn->d_btn->state = false;
            }
        }
    }
}

int main(void) {
    //struct dinput_btn_reg d_btns[32];
    struct phy_btn_reg phy_btns[32];
    int phy_btn_cnt = 0;
    int d_btn_cnt = 0;
    int i = 0;

    stdio_init_all();

    // Setup uFD buttons.
    // Uses gpios 0-19
    for (i = 0; i < 20; i++) {
        gpio_pull_up(i);
        reg_dinput_btn(global_d_btns + d_btn_cnt, i);
        reg_btn(phy_btns + phy_btn_cnt, global_d_btns + d_btn_cnt, i, 0);
        d_btn_cnt++;
        phy_btn_cnt++;
    }
    global_d_btn_cnt = d_btn_cnt;

    // Setup for Pimironi Unicorn Buttons
    //
    //gpio_pull_up(12);
    //reg_dinput_btn(global_d_btns + d_btn_cnt, 0);
    //reg_btn(phy_btns + phy_btn_cnt, global_d_btns + d_btn_cnt, 12, 0);
    //d_btn_cnt++; phy_btn_cnt++;
    //gpio_pull_up(13);
    //reg_dinput_btn(global_d_btns + d_btn_cnt, 1);
    //reg_btn(phy_btns + phy_btn_cnt, global_d_btns + d_btn_cnt, 13, 0);
    //d_btn_cnt++; phy_btn_cnt++;
    //gpio_pull_up(14);
    //reg_dinput_btn(global_d_btns + d_btn_cnt, 2);
    //reg_btn(phy_btns + phy_btn_cnt, global_d_btns + d_btn_cnt, 14, 0);
    //d_btn_cnt++; phy_btn_cnt++;
    //gpio_pull_up(15);
    //reg_dinput_btn(global_d_btns + d_btn_cnt, 3);
    //reg_btn(phy_btns + phy_btn_cnt, global_d_btns + d_btn_cnt, 15, 0);
    //d_btn_cnt++; phy_btn_cnt++;

    board_init();
    tusb_init();

    while (1) {
        tud_task(); // tinyusb device task
        led_blinking_task();
        poll_registered_gpios(phy_btns, phy_btn_cnt);
        hid_task();
    }

    return 0;
}

//--------------------------------------------------------------------+
// Device callbacks
//--------------------------------------------------------------------+

// Invoked when device is mounted
void tud_mount_cb(void) {
    return;
}

// Invoked when device is unmounted
void tud_umount_cb(void) {
    return;
}

// Invoked when usb bus is suspended
// remote_wakeup_en : if host allow us  to perform remote wakeup
// Within 7ms, device must draw an average of current less than 2.5 mA from bus
void tud_suspend_cb(bool remote_wakeup_en) {
    (void)remote_wakeup_en;
    return;
}

// Invoked when usb bus is resumed
void tud_resume_cb(void) { blink_interval_ms = 1500; }

//--------------------------------------------------------------------+
// USB HID
//--------------------------------------------------------------------+

static int send_hid_report() {
    struct dinput_btn_reg *d_btn;
    uint32_t button_state = 0;

    // skip if hid is not ready yet
    if (!tud_hid_ready()) {
        return -1;
    }

    for (d_btn = global_d_btns; d_btn < global_d_btns + global_d_btn_cnt; d_btn++) {
        if (d_btn->btn_id > MAX_DINPUT_BTN_ID || d_btn->btn_id < 0) {
            // Do we want to check here? This takes time. We could just validate at registration..
            continue;
        }
        button_state |= (d_btn->state << d_btn->btn_id);
    }

    hid_gamepad_report_t report = {.x = 50,
                                   .y = 0,
                                   .z = 0,
                                   .rz = 0,
                                   .rx = 0,
                                   .ry = 0,
                                   .hat = global_hat_state,
                                   .buttons = button_state};
    tud_hid_report(REPORT_ID_GAMEPAD, &report, sizeof(report));
}

// Every 1ms, we will sent 1 report for each HID profile (keyboard, mouse etc
// ..) tud_hid_report_complete_cb() is used to send the next report after
// previous one is complete
void hid_task(void) {
    const uint32_t interval_ms = 1;
    static uint32_t start_ms = 0;

    if (board_millis() - start_ms < interval_ms)
        return; // not enough time
    start_ms += interval_ms;

    send_hid_report();
}

// Invoked when sent REPORT successfully to host
// Application can use this to send the next report
// Note: For composite reports, report[0] is report ID
void tud_hid_report_complete_cb(uint8_t instance, uint8_t const *report,
                                uint16_t len) {
    (void)instance;
    (void)len;

    uint8_t next_report_id = report[0] + 1;

    if (next_report_id < REPORT_ID_COUNT) {
        send_hid_report(next_report_id, board_button_read());
    }
}

// Invoked when received GET_REPORT control request
// Application must fill buffer report's content and return its length.
// Return zero will cause the stack to STALL request
uint16_t tud_hid_get_report_cb(uint8_t instance, uint8_t report_id,
                               hid_report_type_t report_type, uint8_t *buffer,
                               uint16_t reqlen) {
    // TODO not Implemented
    (void)instance;
    (void)report_id;
    (void)report_type;
    (void)buffer;
    (void)reqlen;

    return 0;
}

// Invoked when received SET_REPORT control request or
// received data on OUT endpoint ( Report ID = 0, Type = 0 )
void tud_hid_set_report_cb(uint8_t instance, uint8_t report_id,
                           hid_report_type_t report_type, uint8_t const *buffer,
                           uint16_t bufsize) {
    (void)instance;

    if (report_type == HID_REPORT_TYPE_OUTPUT) {
        // Set keyboard LED e.g Capslock, Numlock etc...
        if (report_id == REPORT_ID_KEYBOARD) {
            // bufsize should be (at least) 1
            if (bufsize < 1)
                return;

            uint8_t const kbd_leds = buffer[0];

            if (kbd_leds & KEYBOARD_LED_CAPSLOCK) {
                // Capslock On: disable blink, turn led on
                blink_interval_ms = 0;
                board_led_write(true);
            } else {
                // Caplocks Off: back to normal blink
                board_led_write(false);
                blink_interval_ms = 1500;
            }
        }
    }
}

//--------------------------------------------------------------------+
// BLINKING TASK
//--------------------------------------------------------------------+
void led_blinking_task(void) {
    static uint32_t start_ms = 0;
    static bool led_state = false;

    // blink is disabled
    if (!blink_interval_ms)
        return;

    // Blink every interval ms
    if (board_millis() - start_ms < blink_interval_ms)
        return; // not enough time
    start_ms += blink_interval_ms;

    board_led_write(led_state);
    led_state = 1 - led_state; // toggle
}

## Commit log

2022-04-29 Initial Commit
    - Source dir with HID example
    - clang-format config
    - llvm with more 4 tabs
    - Pico-sdk as submodule
2022-05-15 Switch to gpio polling. Remove old crap.
2023-06-25 Update Pico SDK to 1.5.1
2023-06-25 Modify for uMFD prototype
2025-04-08 Finish v1.0
    Uploads all the files used to complete the v1.0 milestone.
    This has been complete for a while now.. but just uploading them.
    [RP2040-Guide.kicad_pcb, RP2040-Guide.kicad_sch, button-v2.1.blend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]
